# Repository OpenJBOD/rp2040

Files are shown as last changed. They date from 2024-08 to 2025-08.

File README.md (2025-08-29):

# OpenJBOD RP2040 Baseboard

This repository contains the hardware design files OpenJBOD RP2040 Baseboard.

For the accompanying software, please refer to:
- [micropython/micropython](https://github.com/micropython/micropython)
- [OpenJBOD/software](https://github.com/OpenJBOD/software)

## Requirements

- The design was created on KiCad 8.0.2, it uses the default symbol and footprint libraries from it. If you have installed KiCad without the default libraries, you may experience missing symbols.
- Non-standard symbols, footprints and models are bundled in the repository and should load with the project.

## Compatibility

The board is compatible with any standards-compliant ATX power supply.

For SAS expanders, any SAS expander that can operate with only power (i.e. no PCI-e communication) should be functional on the board.

The board has successfully been tested with:

- Adaptec AEC-82885T

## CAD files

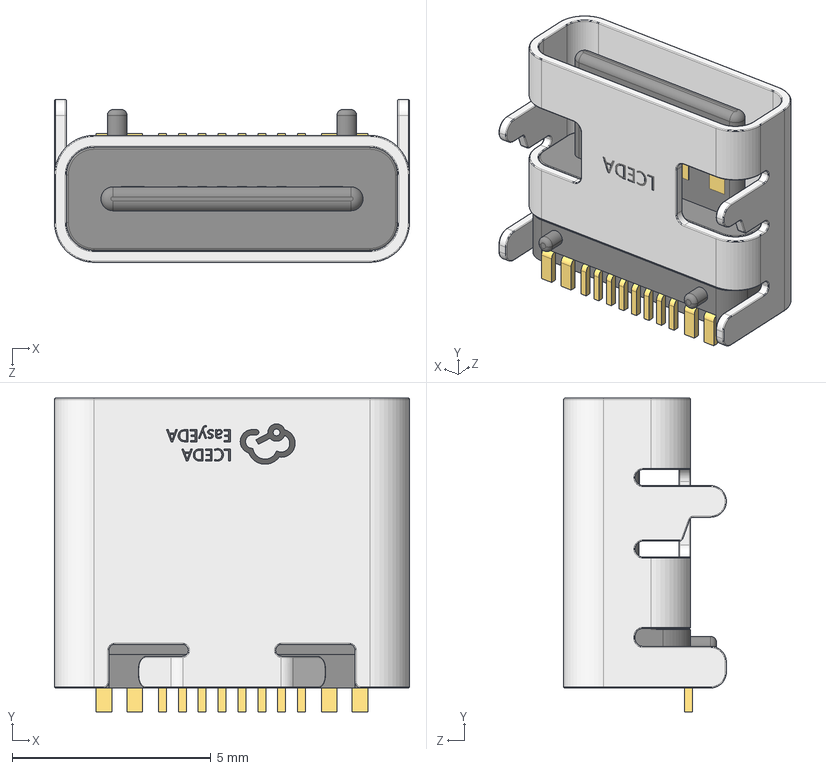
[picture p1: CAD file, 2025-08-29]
OpenJBOD.3d/USB-C-SMD_TYPE-C16PIN.step
8.94 x 7.90 x 4.10 mm

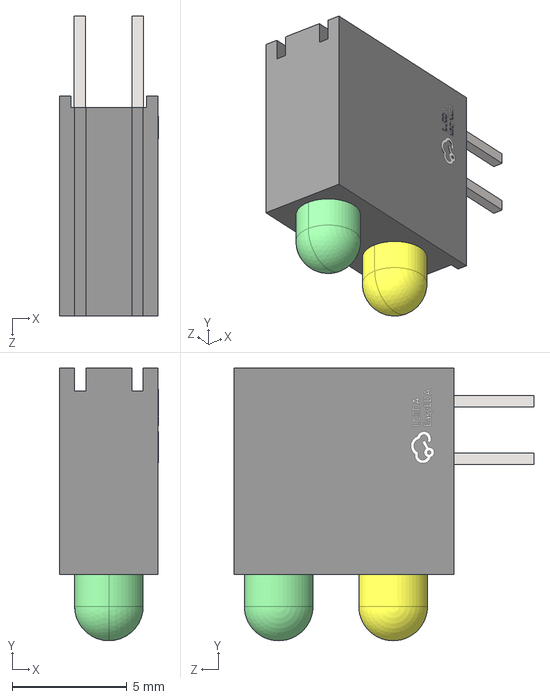
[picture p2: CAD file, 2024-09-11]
OpenJBOD.3d/LED-TH_MHK2396YGBTD.step
4.31 x 11.9 x 13.1 mm

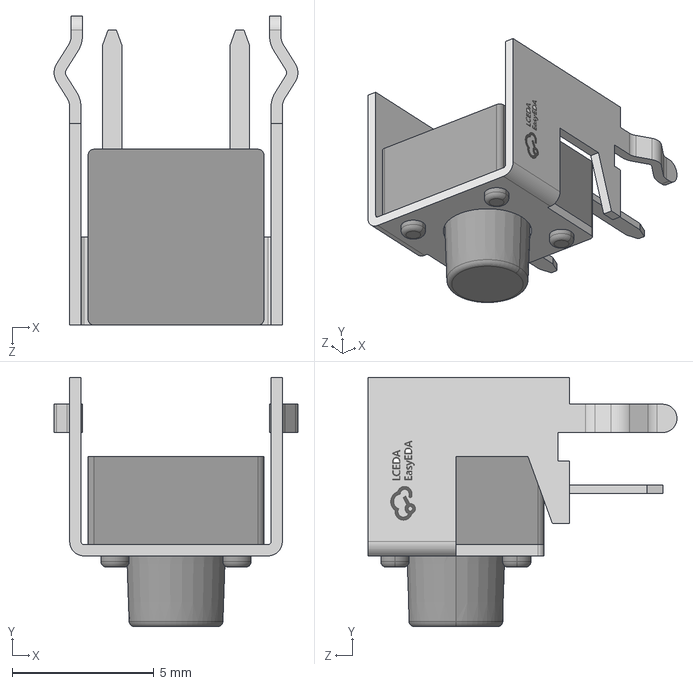
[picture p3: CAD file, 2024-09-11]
OpenJBOD.3d/KEY-TH_TC-6615-6-160G.step
8.60 x 8.80 x 10.9 mm

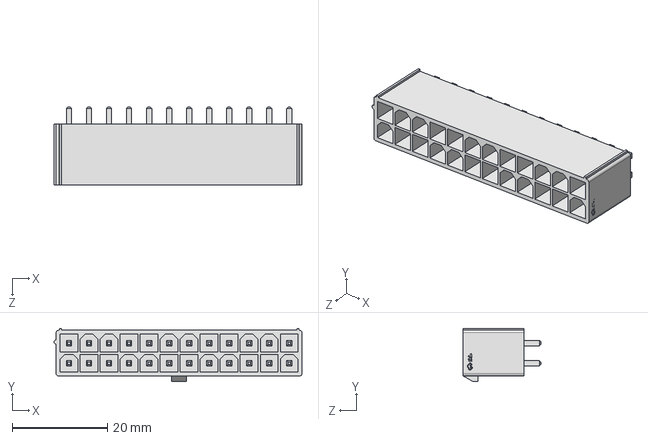
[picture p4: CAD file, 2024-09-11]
OpenJBOD.3d/CONN-TH_M4202V-2X12P.step
52.0 x 11.2 x 16.3 mm

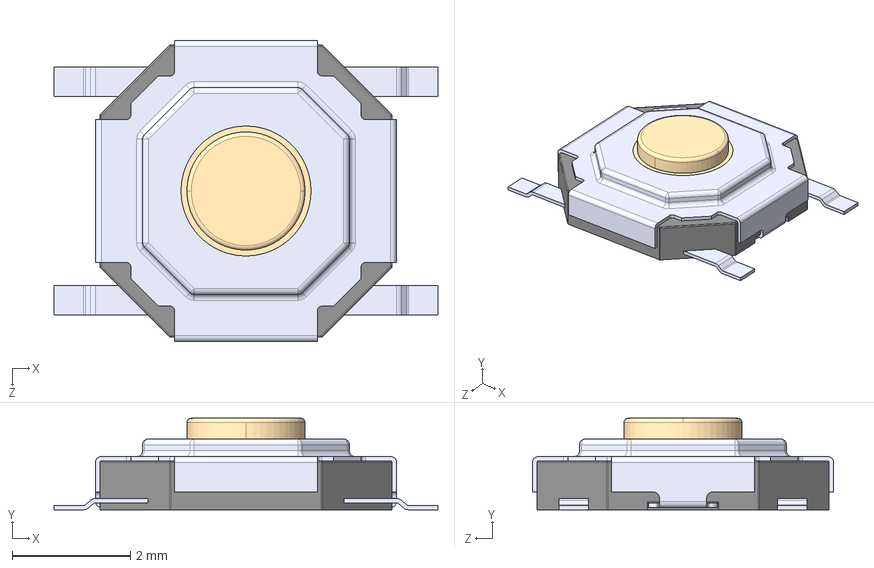
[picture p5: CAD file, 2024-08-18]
OpenJBOD.3d/TS-1187A-B-A-B.STEP
6.50 x 1.55 x 5.10 mm

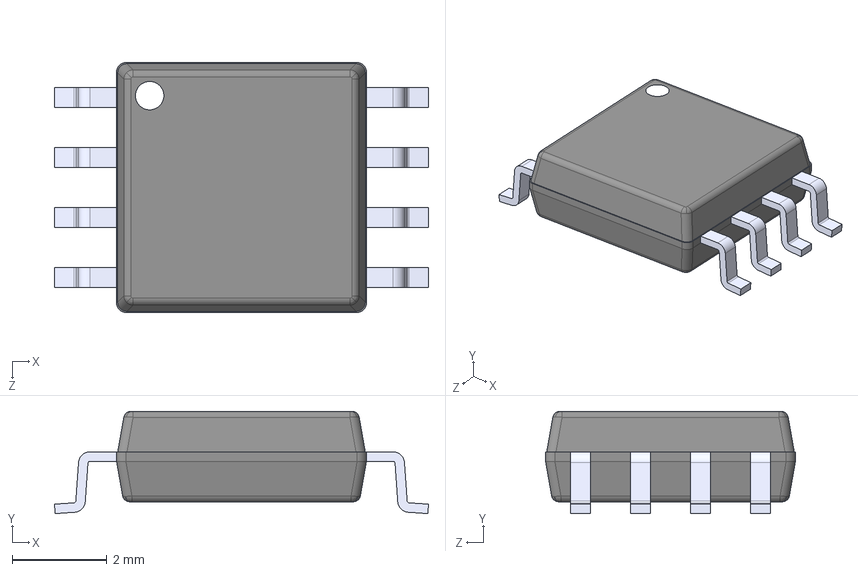
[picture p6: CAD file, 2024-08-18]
OpenJBOD.3d/W25Q128JVSIM TR.STEP
7.90 x 2.16 x 5.28 mm

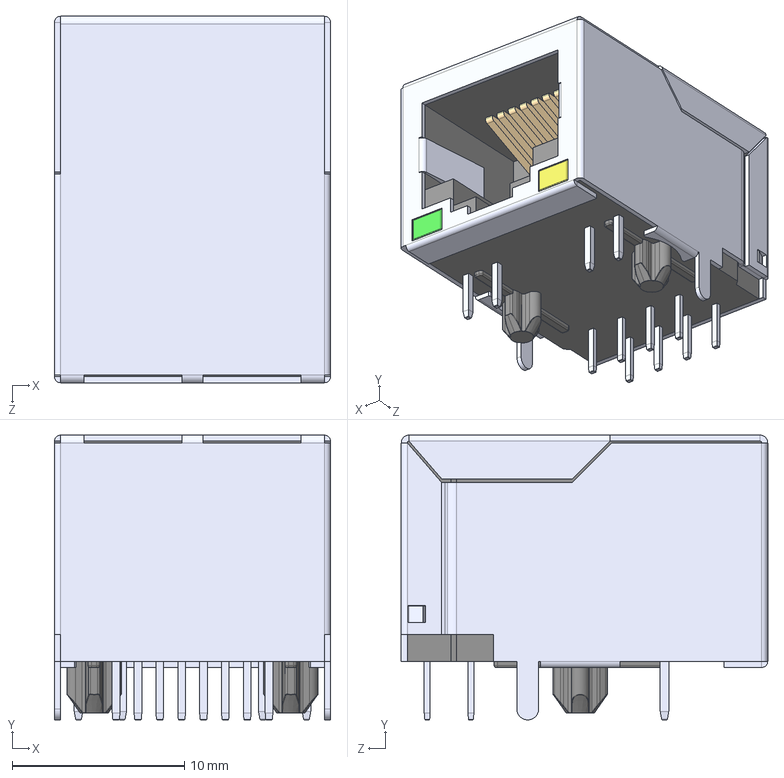
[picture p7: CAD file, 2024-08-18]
OpenJBOD.3d/HR911105A.STEP
16.0 x 16.6 x 21.3 mm

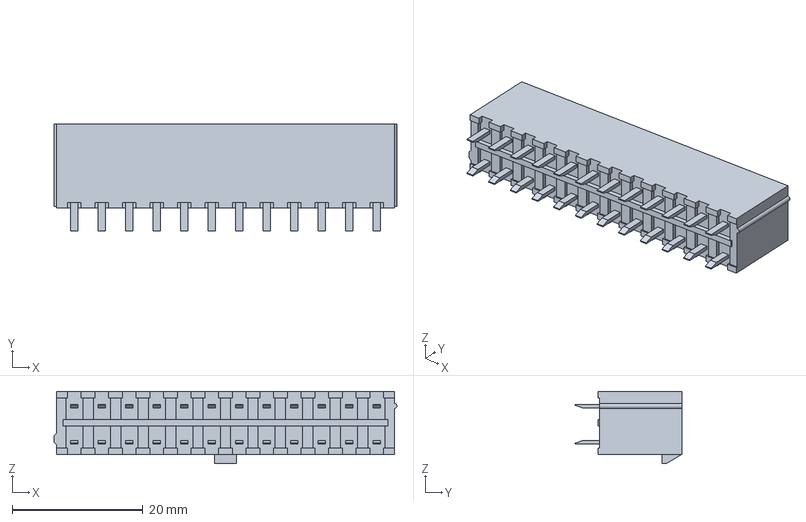
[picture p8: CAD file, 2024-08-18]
OpenJBOD.3d/039281243.stp
52.4 x 16.3 x 11.0 mm

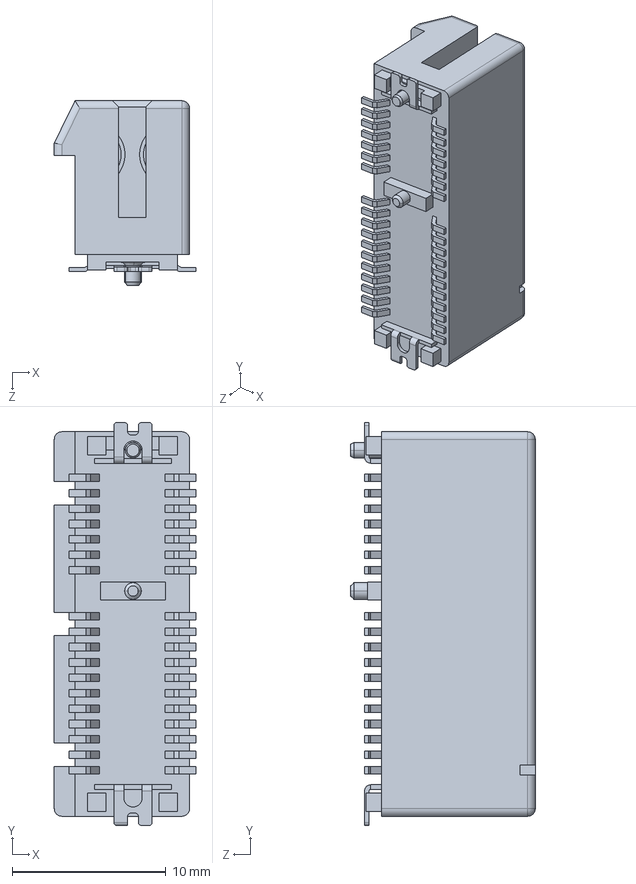
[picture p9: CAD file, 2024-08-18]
OpenJBOD.3d/91618-X1.STEP
9.20 x 26.2 x 12.0 mm

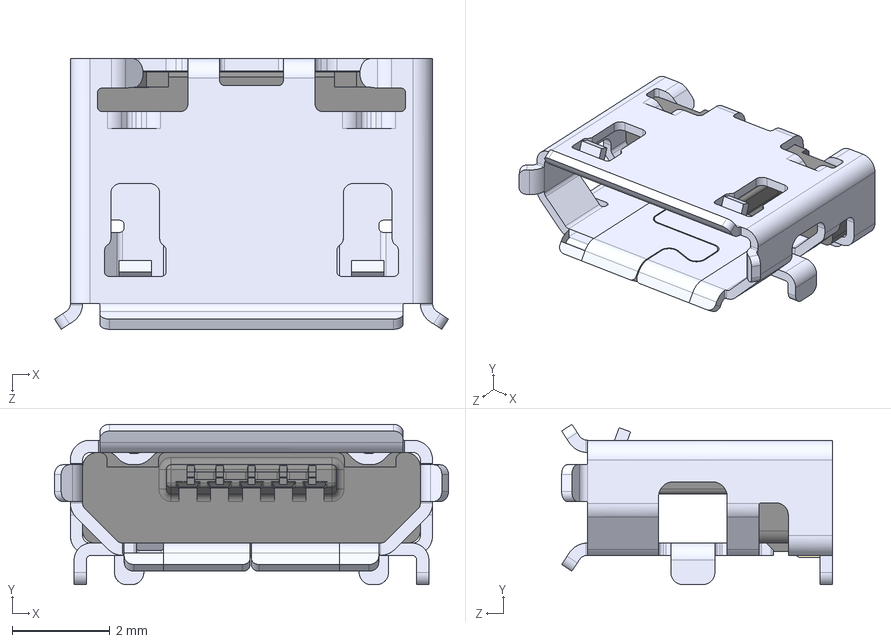
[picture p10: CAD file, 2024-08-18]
OpenJBOD.3d/10118194-0001LF.STEP
8.05 x 3.27 x 5.53 mm

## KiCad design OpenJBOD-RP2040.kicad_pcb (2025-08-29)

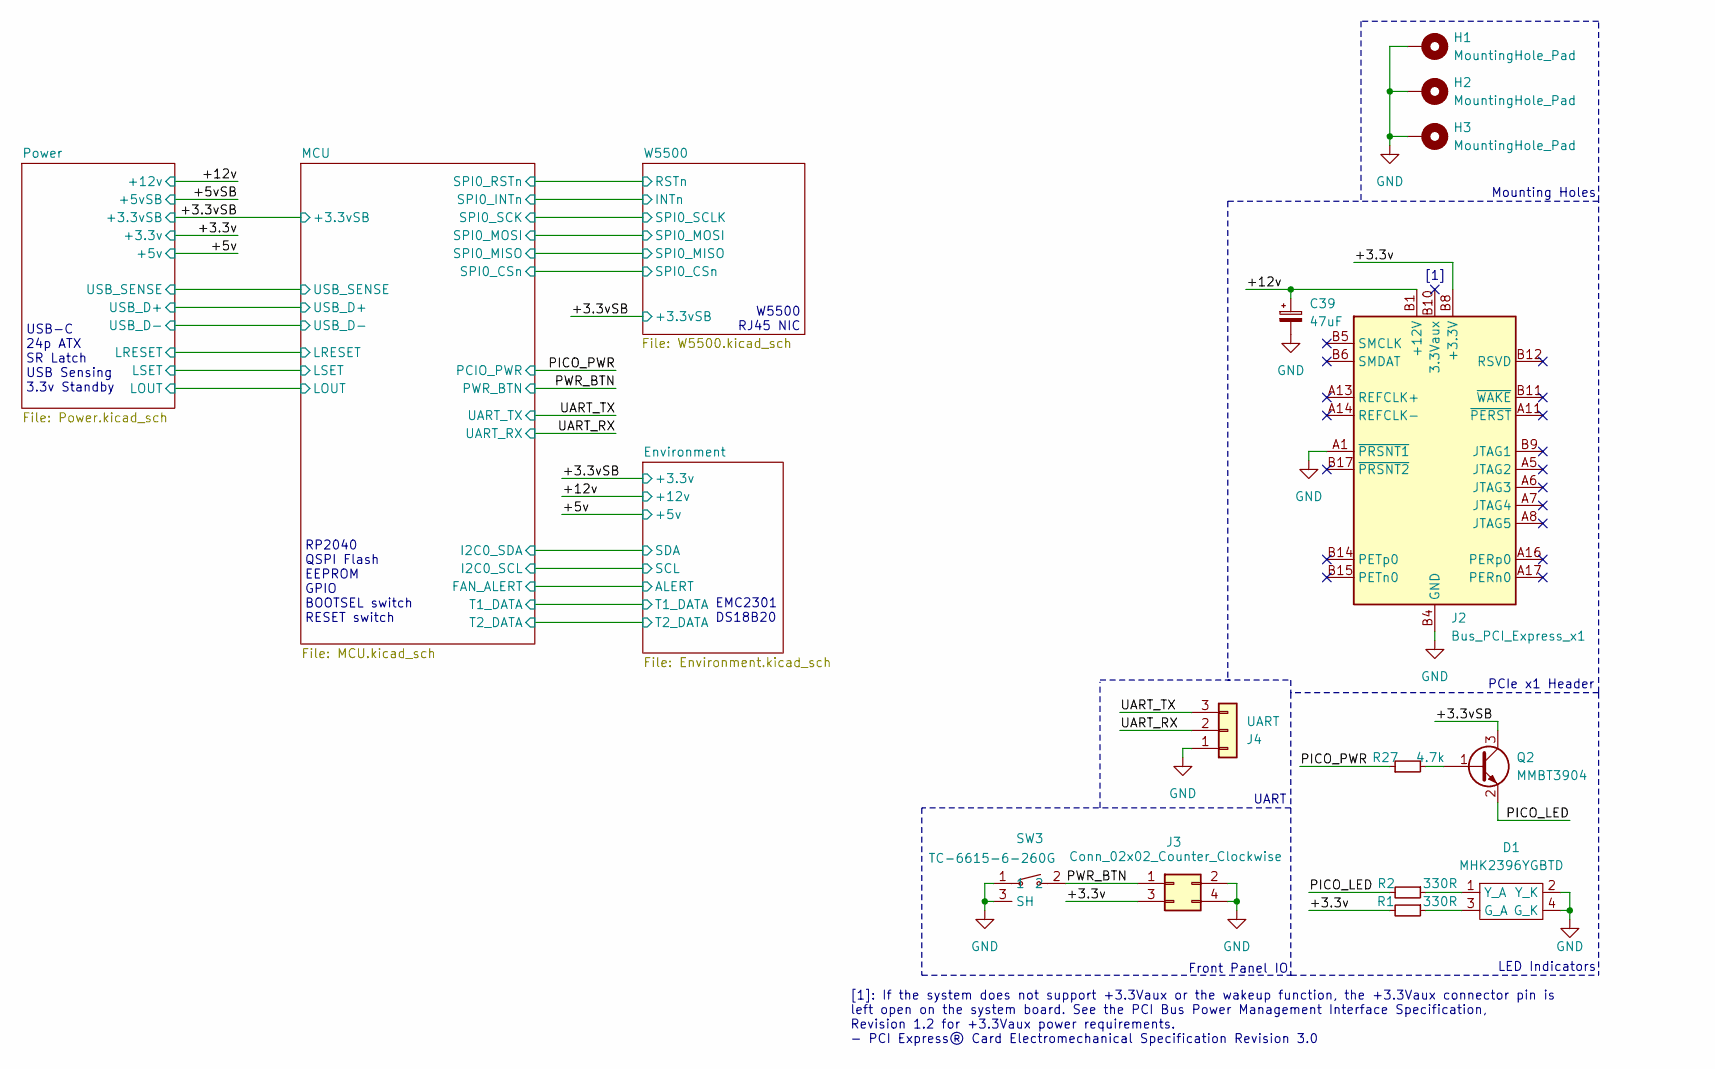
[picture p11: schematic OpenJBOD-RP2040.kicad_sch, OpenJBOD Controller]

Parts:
C39: 47uF; CP_Elec_6.3x5.4; LCSC Part # C2836440
D1: MHK2396YGBTD; LED-TH_MHK2396YGBTD; LCSC Part # C2764899
H1, H2, H3: MountingHole_Pad; MountingHole_4.3mm_M4_Pad_Via
J2: Bus_PCI_Express_x1; 91618-11010C; LCSC Part # C5210918
J3: Conn_02x02_Counter_Clockwise; PinHeader_2x02_P2.54mm_Vertical; LCSC Part # C492419
J4: UART; PinHeader_1x03_P2.54mm_Horizontal; LCSC Part # C2894945
Q2: MMBT3904; SOT-23; LCSC Part # C20526
R1, R2: 330R; R_0402_1005Metric; LCSC Part # C25104
R27: 4.7k; R_0402_1005Metric; LCSC Part # C25900
SW3: TC-6615-6-260G; KEY-TH_TC-6615-6-160G; LCSC Part # C2845272

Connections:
/+3.3v: J2.A9 (+3.3V), J2.A10 (+3.3V), J2.B8 (+3.3V), J3.3, R1.2; also elsewhere on the board
/+3.3vSB: Q2.3 (C); also elsewhere on the board
/+12v: C39.1, J2.A2 (+12V), J2.A3 (+12V), J2.B1 (+12V), J2.B2 (+12V), J2.B3 (+12V); also elsewhere on the board
/PICO_LED: Q2.2 (E), R2.2
/PICO_PWR: R27.1; also elsewhere on the board
/PWR_BTN: J3.1, SW3.2; also elsewhere on the board
/UART_RX: J4.2; also elsewhere on the board
/UART_TX: J4.3; also elsewhere on the board
GND: C39.2, D1.2 (Y_K), D1.4 (G_K), H1.1, H2.1, H3.1, J2.A1 (~PRSNT1), J2.A4 (GND), J2.A12 (GND), J2.A15 (GND), J2.A18 (GND), J2.B4 (GND), J2.B7 (GND), J2.B13 (GND), J2.B16 (GND), J2.B18 (GND), J3.2, J3.4, J4.1, SW3.1, SW3.3 (SH), SW3.4 (SH); also elsewhere on the board
unnamed: D1.3 (G_A), R1.1
unnamed: D1.1 (Y_A), R2.1
unnamed: Q2.1 (B), R27.2

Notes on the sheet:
UART
RP2040 QSPI Flash EEPROM GPIO BOOTSEL switch RESET switch
Mounting Holes
Front Panel IO
EMC2301 DS18B20
LED Indicators
W5500 RJ45 NIC
USB-C 24p ATX SR Latch USB Sensing 3.3v Standby
PCIe x1 Header
[1]: If the system does not support +3.3Vaux or the wakeup function, the +3.3Vaux connector pin is left open on the system board. See the PCI Bus Power Management Interface Specification, Revision 1.2 for +3.3Vaux power requirements. - PCI Express® Card Electromechanical Specification Revision 3.0
[1]

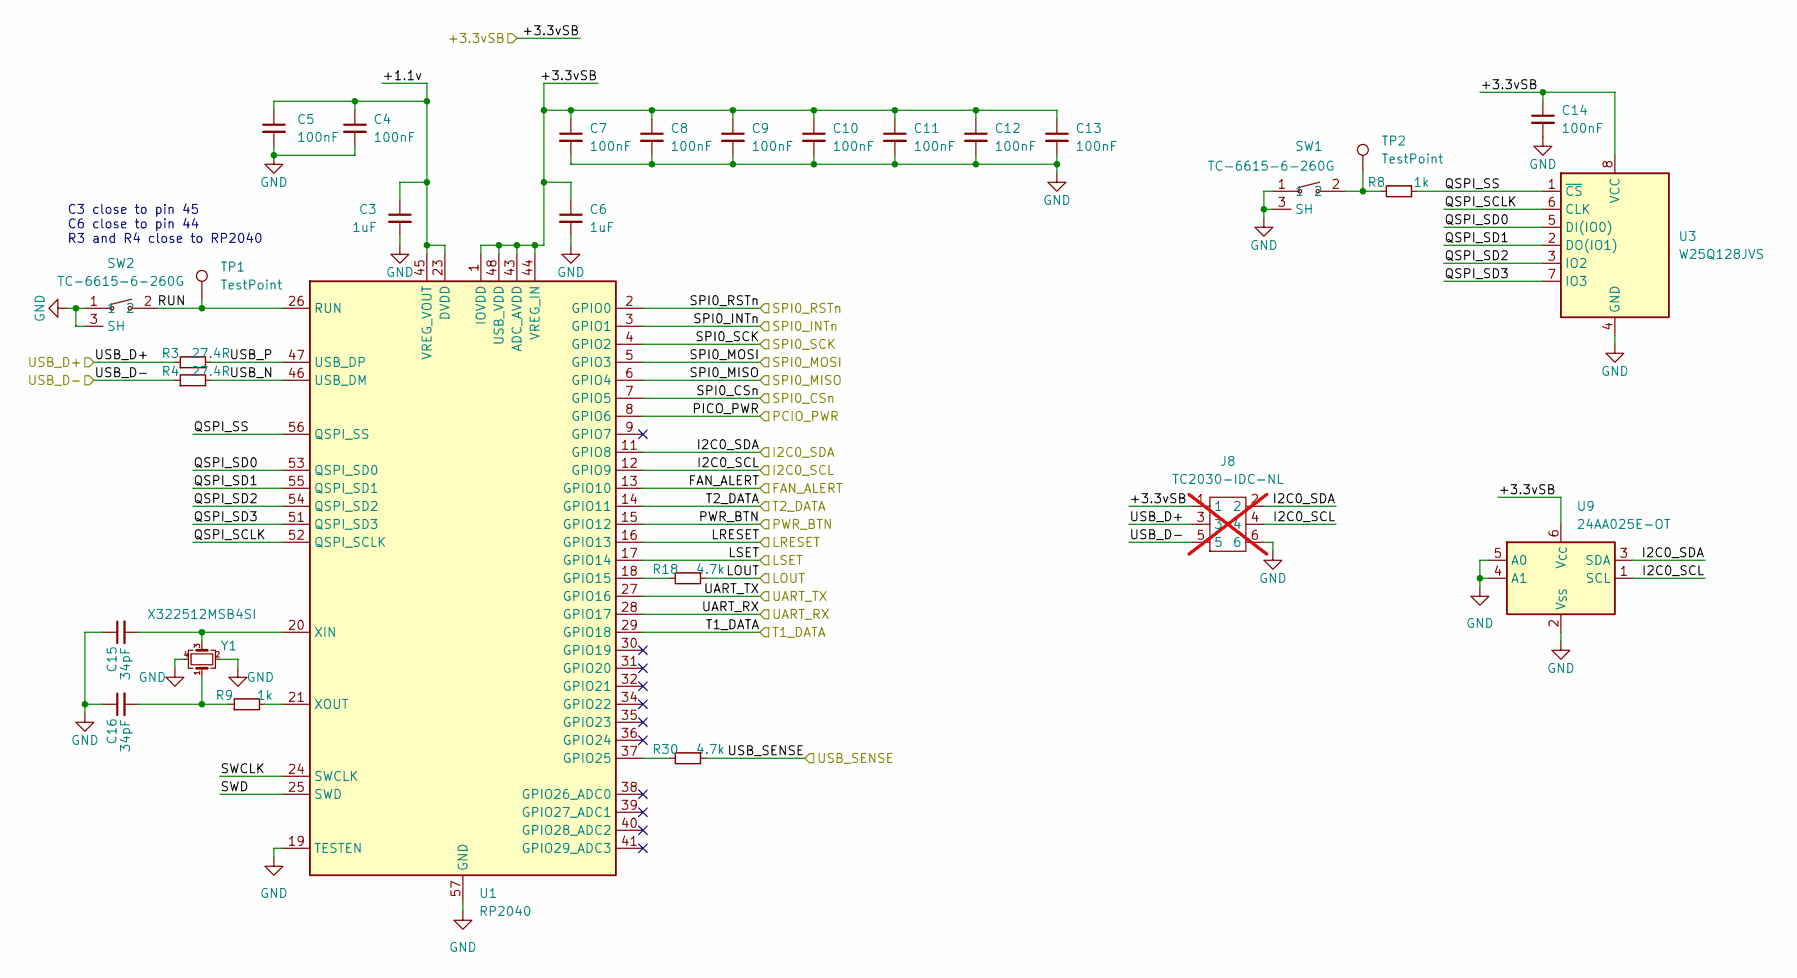
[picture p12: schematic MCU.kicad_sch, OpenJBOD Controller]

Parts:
C3, C6: 1uF; C_0402_1005Metric; LCSC Part # C52923
C4, C5, C7, C8, C9, C10, C11, C12, C13, C14: 100nF; C_0402_1005Metric; LCSC Part # C1525
C15, C16: 34pF; C_0603_1608Metric; LCSC Part # C1658
J8: TC2030-IDC-NL; Tag-Connect_TC2030-IDC-NL_2x03_P1.27mm_Vertical; not fitted
R3, R4: 27.4R; R_0402_1005Metric; LCSC Part # C284479
R8, R9: 1k; R_0402_1005Metric; LCSC Part # C11702
R18, R30: 4.7k; R_0402_1005Metric; LCSC Part # C25900
SW1, SW2: TC-6615-6-260G; KEY-TH_TC-6615-6-160G; LCSC Part # C2845272
TP1, TP2: TestPoint; TestPoint_Pad_D1.0mm
U1: RP2040; QFN-56-1EP_7x7mm_P0.4mm_EP3.2x3.2mm; LCSC Part # C2040
U3: W25Q128JVS; SOIC-8_5.23x5.23mm_P1.27mm; LCSC Part # C97521
U9: 24AA025E-OT; SOT-23-6; LCSC Part # C129895
Y1: X322512MSB4SI; Crystal_SMD_3225-4Pin_3.2x2.5mm; LCSC Part # C9002

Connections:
/+3.3vSB: C6.1, C7.1, C8.1, C9.1, C10.1, C11.1, C12.1, C13.1, C14.1, J8.1, U1.1 (IOVDD), U1.10 (IOVDD), U1.22 (IOVDD), U1.33 (IOVDD), U1.42 (IOVDD), U1.43 (ADC_AVDD), U1.44 (VREG_IN), U1.48 (USB_VDD), U1.49 (IOVDD), U3.8 (VCC), U9.6 (V_{CC}); also elsewhere on the board
/Environment/ALERT: U1.13 (GPIO10); also elsewhere on the board
/Environment/SCL: J8.4, U1.12 (GPIO9), U9.1 (SCL); also elsewhere on the board
/Environment/SDA: J8.2, U1.11 (GPIO8), U9.3 (SDA); also elsewhere on the board
/Environment/T1_DATA: U1.29 (GPIO18); also elsewhere on the board
/Environment/T2_DATA: U1.14 (GPIO11); also elsewhere on the board
/MCU/+1.1v: C3.1, C4.1, C5.1, U1.23 (DVDD), U1.45 (VREG_VOUT), U1.50 (DVDD)
/MCU/LOUT: R18.1; also elsewhere on the board
/MCU/LRESET: U1.16 (GPIO13); also elsewhere on the board
/MCU/LSET: U1.17 (GPIO14); also elsewhere on the board
/MCU/QSPI_SCLK: U1.52 (QSPI_SCLK), U3.6 (CLK)
/MCU/QSPI_SD0: U1.53 (QSPI_SD0), U3.5 (DI(IO0))
/MCU/QSPI_SD1: U1.55 (QSPI_SD1), U3.2 (DO(IO1))
/MCU/QSPI_SD2: U1.54 (QSPI_SD2), U3.3 (IO2)
/MCU/QSPI_SD3: U1.51 (QSPI_SD3), U3.7 (IO3)
/MCU/QSPI_SS: R8.1, U1.56 (QSPI_SS), U3.1 (~CS)
/MCU/RUN: SW2.2, TP1.1, U1.26 (RUN)
/MCU/SPI0_CSn: U1.7 (GPIO5); also elsewhere on the board
/MCU/SPI0_INTn: U1.3 (GPIO1); also elsewhere on the board
/MCU/SPI0_MISO: U1.6 (GPIO4); also elsewhere on the board
/MCU/SPI0_MOSI: U1.5 (GPIO3); also elsewhere on the board
/MCU/SPI0_RSTn: U1.2 (GPIO0); also elsewhere on the board
/MCU/SPI0_SCK: U1.4 (GPIO2); also elsewhere on the board
/MCU/SWCLK: U1.24 (SWCLK)
/MCU/SWD: U1.25 (SWD)
/MCU/USB_D+: J8.3, R3.1; also elsewhere on the board
/MCU/USB_D-: J8.5, R4.1; also elsewhere on the board
/MCU/USB_N: R4.2, U1.46 (USB_DM)
/MCU/USB_P: R3.2, U1.47 (USB_DP)
/MCU/USB_SENSE: R30.1; also elsewhere on the board
/PICO_PWR: U1.8 (GPIO6); also elsewhere on the board
/PWR_BTN: U1.15 (GPIO12); also elsewhere on the board
/UART_RX: U1.28 (GPIO17); also elsewhere on the board
/UART_TX: U1.27 (GPIO16); also elsewhere on the board
GND: C3.2, C4.2, C5.2, C6.2, C7.2, C8.2, C9.2, C10.2, C11.2, C12.2, C13.2, C14.2, C15.1, C16.1, J8.6, SW1.1, SW1.3 (SH), SW1.4 (SH), SW2.1, SW2.3 (SH), SW2.4 (SH), U1.19 (TESTEN), U1.57 (GND), U3.4 (GND), U9.2 (V_{SS}), U9.4 (A1), U9.5 (A0), Y1.2, Y1.4; also elsewhere on the board
unnamed: C16.2, R9.1, Y1.1
unnamed: R8.2, SW1.2, TP2.1
unnamed: R18.2, U1.18 (GPIO15)
unnamed: R30.2, U1.37 (GPIO25)
unnamed: C15.2, U1.20 (XIN), Y1.3
unnamed: R9.2, U1.21 (XOUT)

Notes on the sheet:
C3 close to pin 45 C6 close to pin 44 R3 and R4 close to RP2040

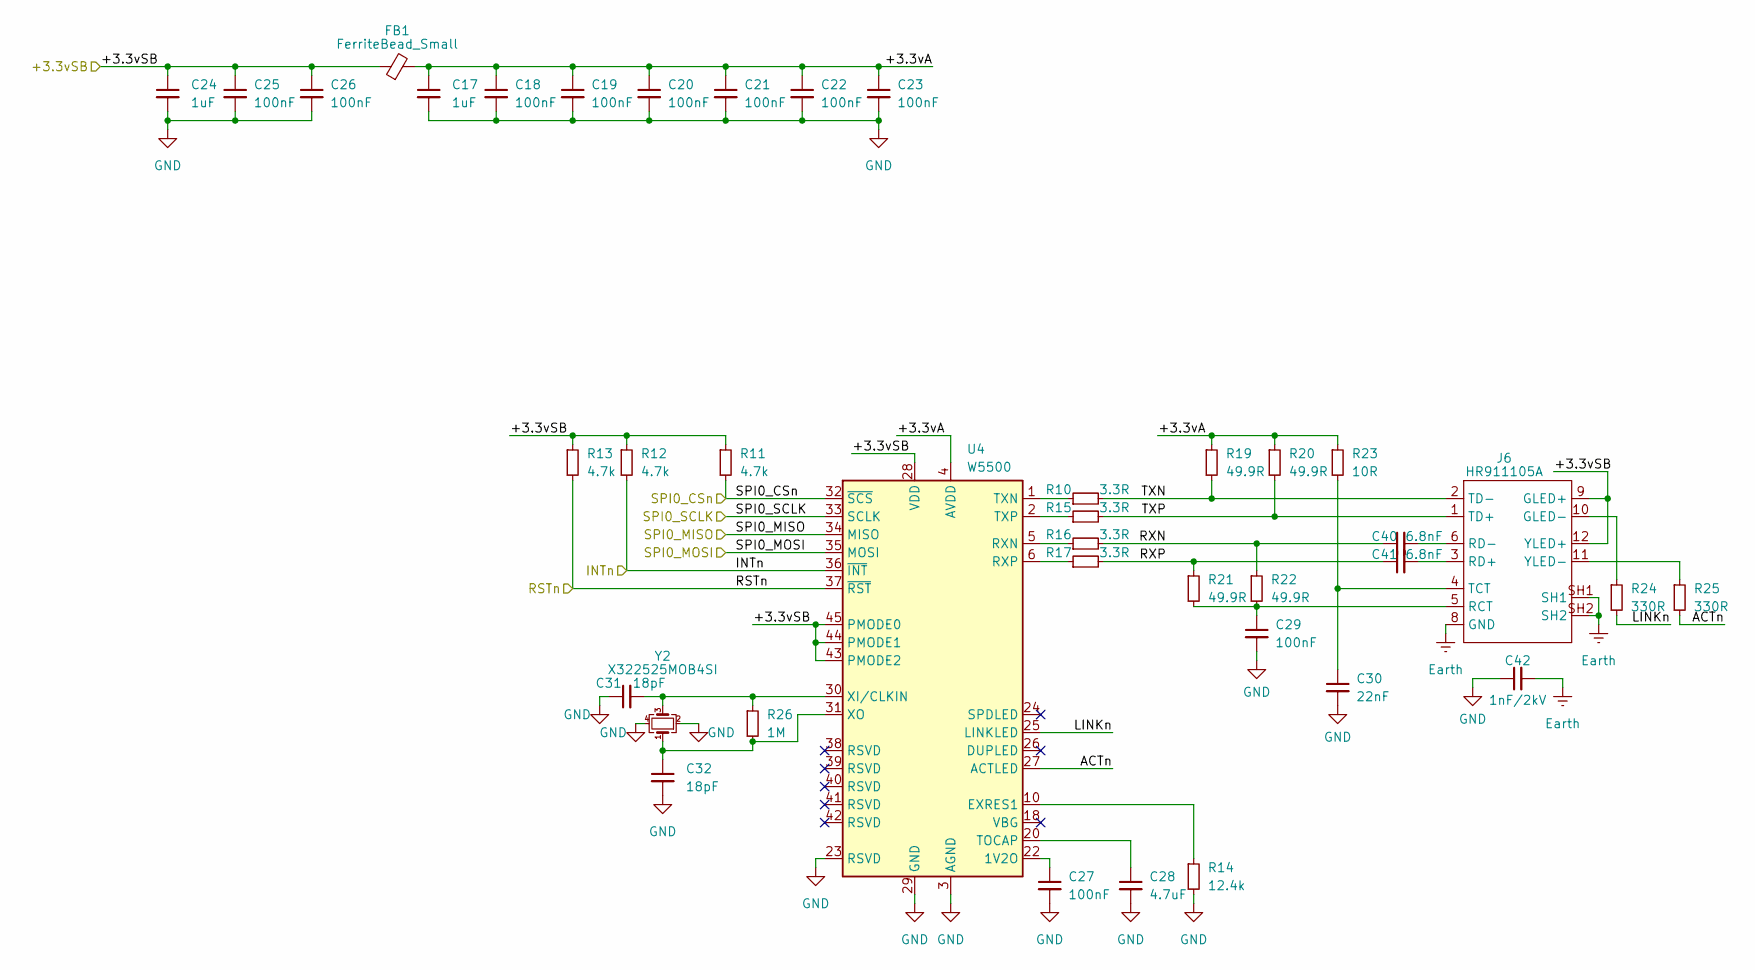
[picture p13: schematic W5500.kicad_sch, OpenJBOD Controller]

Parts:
C17, C24: 1uF; C_0402_1005Metric; LCSC Part # C52923
C18, C19, C20, C21, C22, C23, C25, C26, C27, C29: 100nF; C_0402_1005Metric; LCSC Part # C1525
C28: 4.7uF; C_0402_1005Metric; LCSC Part # C23733
C30: 22nF; C_0402_1005Metric; LCSC Part # C1532
C31, C32: 18pF; C_0402_1005Metric; LCSC Part # C1549
C40, C41: 6.8nF; C_0402_1005Metric; LCSC Part # C1542
C42: 1nF/2kV; C_1206_3216Metric; LCSC Part # C9196
FB1: FerriteBead_Small; C_0805_2012Metric_Pad1.18x1.45mm_HandSolder; LCSC Part # C1015
J6: HR911105A; RJ45-TH_HR911105A; LCSC Part # C12074
R10, R15, R16, R17: 3.3R; R_0603_1608Metric; LCSC Part # C2930016
R11, R12, R13: 4.7k; R_0402_1005Metric; LCSC Part # C25900
R14: 12.4k; R_0402_1005Metric; LCSC Part # C11692
R19, R20, R21, R22: 49.9R; R_0402_1005Metric; LCSC Part # C25120
R23: 10R; R_0402_1005Metric; LCSC Part # C25077
R24, R25: 330R; R_0402_1005Metric; LCSC Part # C25104
R26: 1M; R_0402_1005Metric; LCSC Part # C26083
U4: W5500; LQFP-48_7x7mm_P0.5mm; LCSC Part # C32843
Y2: X322525MOB4SI; Crystal_SMD_3225-4Pin_3.2x2.5mm; LCSC Part # C9006

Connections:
/+3.3vSB: C24.1, C25.1, C26.1, FB1.1, J6.9 (GLED+), J6.12 (YLED+), R11.1, R12.1, R13.1, U4.28 (VDD), U4.43 (PMODE2), U4.44 (PMODE1), U4.45 (PMODE0); also elsewhere on the board
/MCU/SPI0_CSn: R11.2, U4.32 (~SCS); also elsewhere on the board
/MCU/SPI0_INTn: R12.2, U4.36 (~INT); also elsewhere on the board
/MCU/SPI0_MISO: U4.34 (MISO); also elsewhere on the board
/MCU/SPI0_MOSI: U4.35 (MOSI); also elsewhere on the board
/MCU/SPI0_RSTn: R13.2, U4.37 (~RST); also elsewhere on the board
/MCU/SPI0_SCK: U4.33 (SCLK); also elsewhere on the board
/W5500/+3.3vA: C17.1, C18.1, C19.1, C20.1, C21.1, C22.1, C23.1, FB1.2, R19.1, R20.1, R23.1, U4.4 (AVDD), U4.8 (AVDD), U4.11 (AVDD), U4.15 (AVDD), U4.17 (AVDD), U4.21 (AVDD)
/W5500/ACTn: R25.2, U4.27 (ACTLED)
/W5500/LINKn: R24.2, U4.25 (LINKLED)
/W5500/RXN: C40.1, R16.2, R22.1
/W5500/RXP: C41.1, R17.2, R21.1
/W5500/TXN: J6.2 (TD-), R10.2, R19.2
/W5500/TXP: J6.1 (TD+), R15.2, R20.2
Earth: C42.2, J6.8 (GND), J6.SH1, J6.SH2
GND: C17.2, C18.2, C19.2, C20.2, C21.2, C22.2, C23.2, C24.2, C25.2, C26.2, C27.2, C28.2, C29.2, C30.2, C31.1, C32.2, C42.1, R14.2, U4.3 (AGND), U4.9 (AGND), U4.14 (AGND), U4.16 (AGND), U4.19 (AGND), U4.23 (RSVD), U4.29 (GND), U4.48 (AGND), Y2.2, Y2.4; also elsewhere on the board
unnamed: J6.10 (GLED-), R24.1
unnamed: C29.1, J6.5 (RCT), R21.2, R22.2
unnamed: C41.2, J6.3 (RD+)
unnamed: C40.2, J6.6 (RD-)
unnamed: C30.1, J6.4 (TCT), R23.2
unnamed: J6.11 (YLED-), R25.1
unnamed: C27.1, U4.22 (1V2O)
unnamed: R14.1, U4.10 (EXRES1)
unnamed: R16.1, U4.5 (RXN)
unnamed: R17.1, U4.6 (RXP)
unnamed: C28.1, U4.20 (TOCAP)
unnamed: R10.1, U4.1 (TXN)
unnamed: R15.1, U4.2 (TXP)
unnamed: C31.2, R26.1, U4.30 (XI/CLKIN), Y2.3
unnamed: C32.1, R26.2, U4.31 (XO), Y2.1

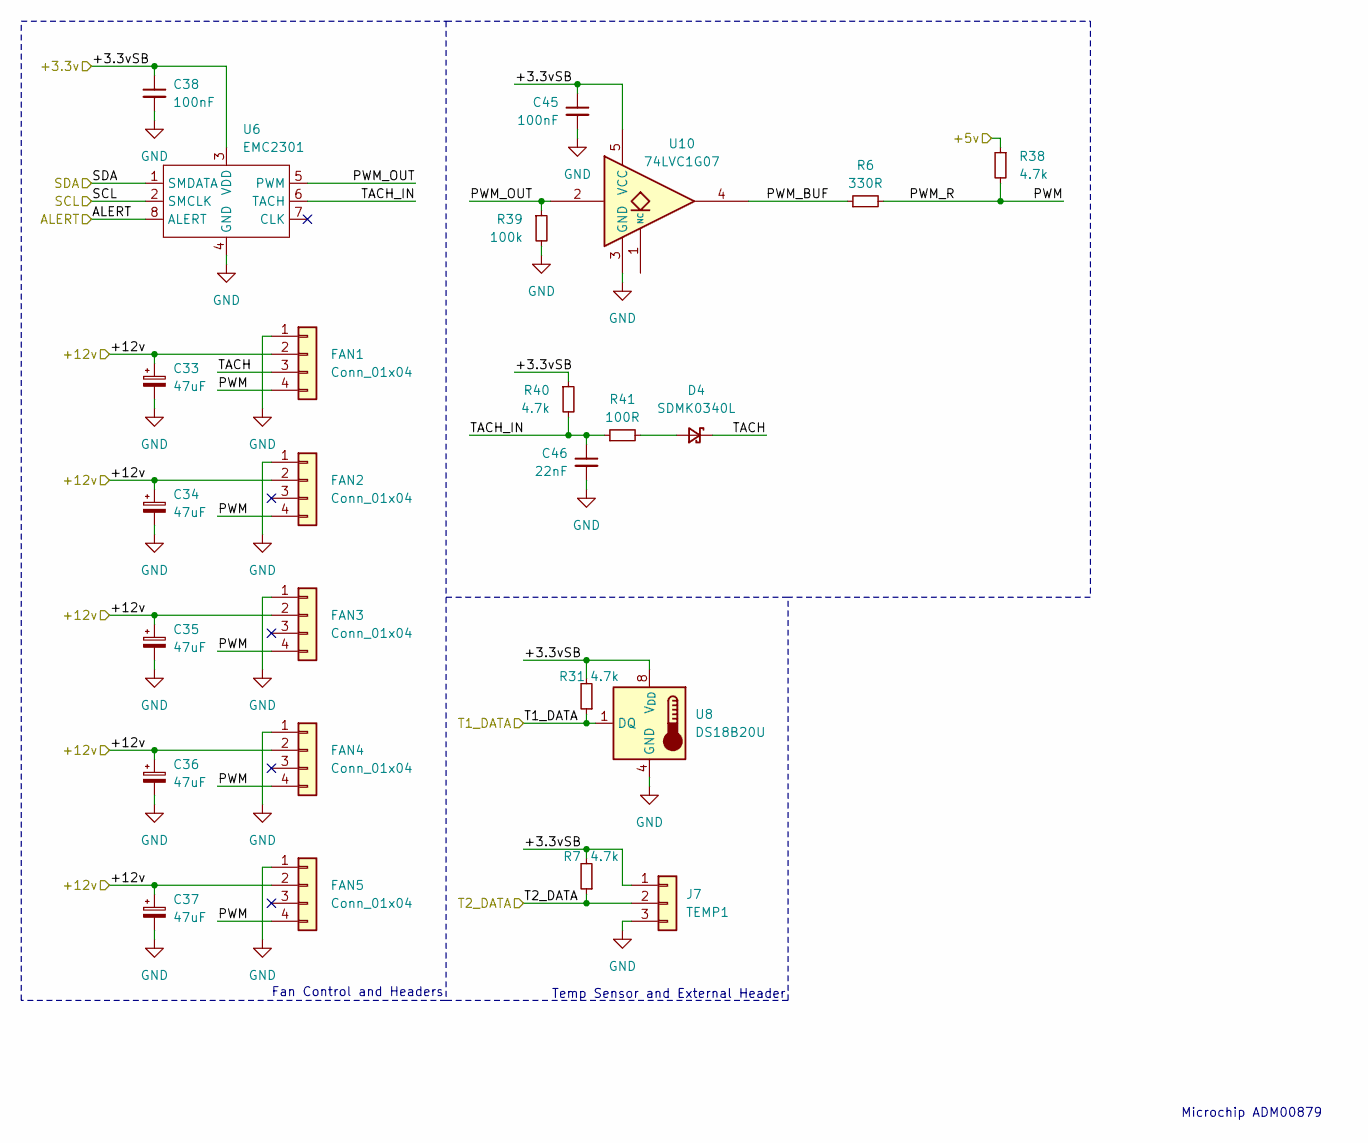
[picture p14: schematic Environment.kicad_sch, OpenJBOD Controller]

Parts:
C33, C34, C35, C36, C37: 47uF; CP_Elec_6.3x5.4; LCSC Part # C2836440
C38, C45: 100nF; C_0402_1005Metric; LCSC Part # C1525
C46: 22nF; C_0402_1005Metric; LCSC Part # C1532
D4: SDMK0340L; D_SOD-323; LCSC Part # C139440
FAN1, FAN2, FAN3, FAN4, FAN5: Conn_01x04; FanPinHeader_1x04_P2.54mm_Vertical; LCSC Part # C240840
J7: TEMP1; PinHeader_1x03_P2.54mm_Vertical; LCSC Part # C2937625
R6: 330R; R_0402_1005Metric; LCSC Part # C25104
R7, R31, R38, R40: 4.7k; R_0402_1005Metric; LCSC Part # C25900
R39: 100k; C_0402_1005Metric; LCSC Part # C25741
R41: 100R; C_0402_1005Metric; LCSC Part # C25076
U6: EMC2301; MSOP-8_3x3mm_P0.65mm; LCSC Part # C148036
U8: DS18B20U; MSOP-8_3x3mm_P0.65mm; LCSC Part # C695836
U10: 74LVC1G07; SOT-23-5; LCSC Part # C7829

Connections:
/+3.3vSB: C38.1, C45.1, J7.1, R7.2, R31.2, R40.1, U6.3 (VDD), U8.8 (V_{DD}), U10.5 (VCC); also elsewhere on the board
/+5v: R38.1; also elsewhere on the board
/+12v: C33.1, C34.1, C35.1, C36.1, C37.1, FAN1.2, FAN2.2, FAN3.2, FAN4.2, FAN5.2; also elsewhere on the board
/Environment/ALERT: U6.8 (ALERT); also elsewhere on the board
/Environment/PWM: FAN1.4, FAN2.4, FAN3.4, FAN4.4, FAN5.4, R6.2, R38.2
/Environment/PWM_BUF: R6.1, U10.4
/Environment/PWM_OUT: R39.1, U6.5 (PWM), U10.2
/Environment/SCL: U6.2 (SMCLK); also elsewhere on the board
/Environment/SDA: U6.1 (SMDATA); also elsewhere on the board
/Environment/T1_DATA: R31.1, U8.1 (DQ); also elsewhere on the board
/Environment/T2_DATA: J7.2, R7.1; also elsewhere on the board
/Environment/TACH: D4.1 (K), FAN1.3
/Environment/TACH_IN: C46.1, R40.2, R41.1, U6.6 (TACH)
GND: C33.2, C34.2, C35.2, C36.2, C37.2, C38.2, C45.2, C46.2, FAN1.1, FAN2.1, FAN3.1, FAN4.1, FAN5.1, J7.3, R39.2, U6.4 (GND), U8.4 (GND), U10.3 (GND); also elsewhere on the board
unnamed: D4.2 (A), R41.2

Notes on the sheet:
Temp Sensor and External Header
Microchip ADM00879
Fan Control and Headers

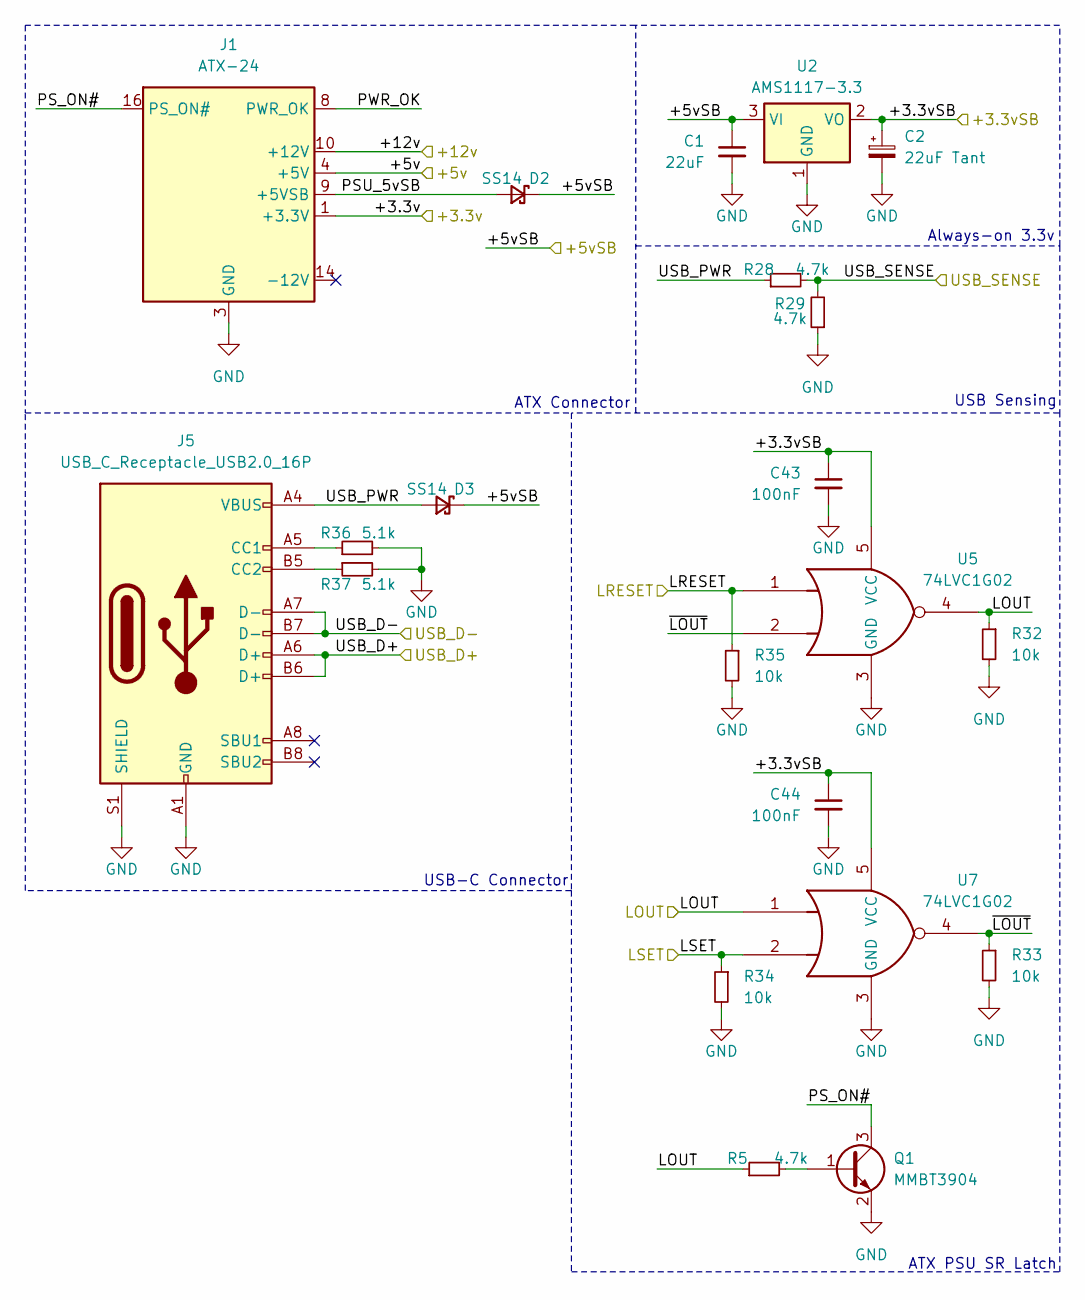
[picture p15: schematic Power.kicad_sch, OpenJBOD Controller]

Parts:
C1: 22uF; C_1206_3216Metric; LCSC Part # C12891
C2: 22uF Tant; CP_EIA-3216-18_Kemet-A; LCSC Part # C11366
C43, C44: 100nF; C_0402_1005Metric; LCSC Part # C1525
D2, D3: SS14; D_SMA; LCSC Part # C2480
J1: ATX-24; CONN-TH_M4202V-2X12P; LCSC Part # C492535
J5: USB_C_Receptacle_USB2.0_16P; USB-C-SMD_TYPE-C16PIN; LCSC Part # C393939
Q1: MMBT3904; SOT-23; LCSC Part # C20526
R5, R28, R29: 4.7k; R_0402_1005Metric; LCSC Part # C25900
R32, R33, R34, R35: 10k; C_0402_1005Metric; LCSC Part # C25744
R36, R37: 5.1k; C_0402_1005Metric; LCSC Part # C25905
U2: AMS1117-3.3; SOT-223-3_TabPin2; LCSC Part # C6186
U5, U7: 74LVC1G02; SOT-353_SC-70-5; LCSC Part # C353856

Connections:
/+3.3v: J1.1 (+3.3V), J1.2 (+3.3V), J1.12 (+3.3V), J1.13 (+3.3V); also elsewhere on the board
/+3.3vSB: C2.1, C43.1, C44.1, U2.2 (VO), U5.5 (VCC), U7.5 (VCC); also elsewhere on the board
/+5v: J1.4 (+5V), J1.6 (+5V), J1.21 (+5V), J1.22 (+5V), J1.23 (+5V); also elsewhere on the board
/+5vSB: C1.1, D2.1 (K), D3.1 (K), U2.3 (VI)
/+12v: J1.10 (+12V), J1.11 (+12V); also elsewhere on the board
/MCU/LOUT: R5.1, R32.1, U5.4, U7.1; also elsewhere on the board
/MCU/LRESET: R35.1, U5.1; also elsewhere on the board
/MCU/LSET: R34.1, U7.2; also elsewhere on the board
/MCU/USB_D+: J5.A6 (D+), J5.B6 (D+); also elsewhere on the board
/MCU/USB_D-: J5.A7 (D-), J5.B7 (D-); also elsewhere on the board
/MCU/USB_SENSE: R28.2, R29.2; also elsewhere on the board
/Power/PSU_5vSB: D2.2 (A), J1.9 (+5VSB)
/Power/PS_ON#: J1.16 (PS_ON#), Q1.3 (C)
/Power/PWR_OK: J1.8 (PWR_OK)
/Power/USB_PWR: D3.2 (A), J5.A4 (VBUS), J5.A9 (VBUS), J5.B4 (VBUS), J5.B9 (VBUS), R28.1
/Power/~LOUT: R33.1, U5.2, U7.4
GND: C1.2, C2.2, C43.2, C44.2, J1.3 (GND), J1.5 (GND), J1.7 (GND), J1.15 (GND), J1.17 (GND), J1.18 (GND), J1.19 (GND), J1.24 (GND), J5.A1 (GND), J5.A12 (GND), J5.B1 (GND), J5.B12 (GND), J5.S1 (SHIELD), Q1.2 (E), R29.1, R32.2, R33.2, R34.2, R35.2, R36.2, R37.2, U2.1 (GND), U5.3 (GND), U7.3 (GND); also elsewhere on the board
unnamed: J5.A5 (CC1), R36.1
unnamed: J5.B5 (CC2), R37.1
unnamed: Q1.1 (B), R5.2

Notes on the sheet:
USB-C Connector
ATX PSU SR Latch
ATX Connector
USB Sensing
Always-on 3.3v

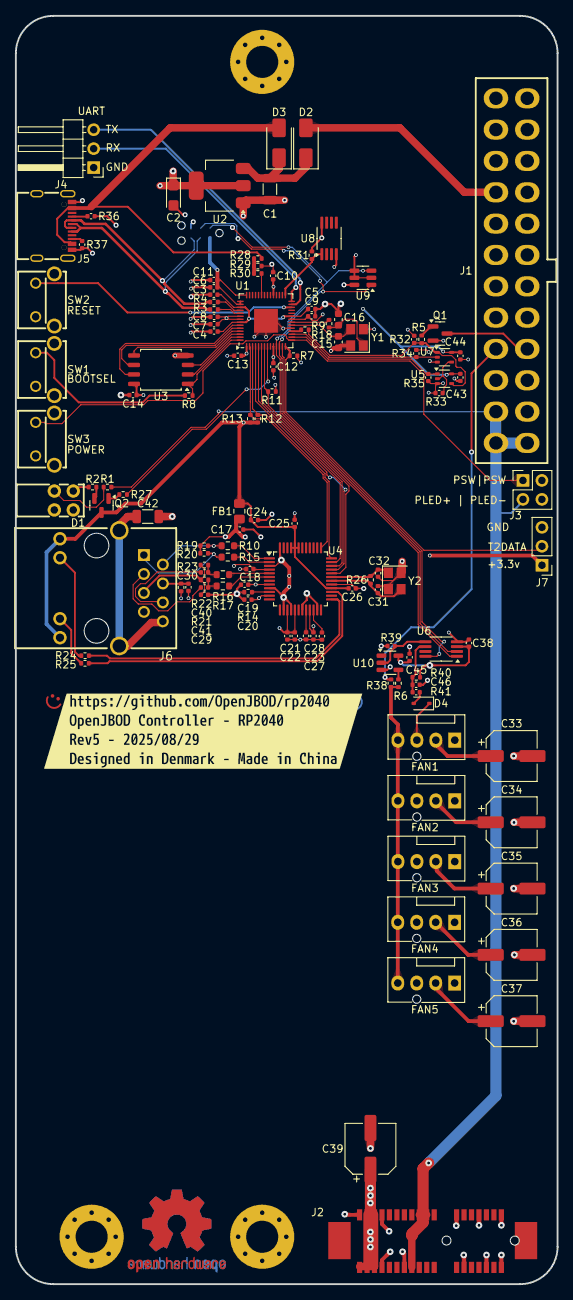
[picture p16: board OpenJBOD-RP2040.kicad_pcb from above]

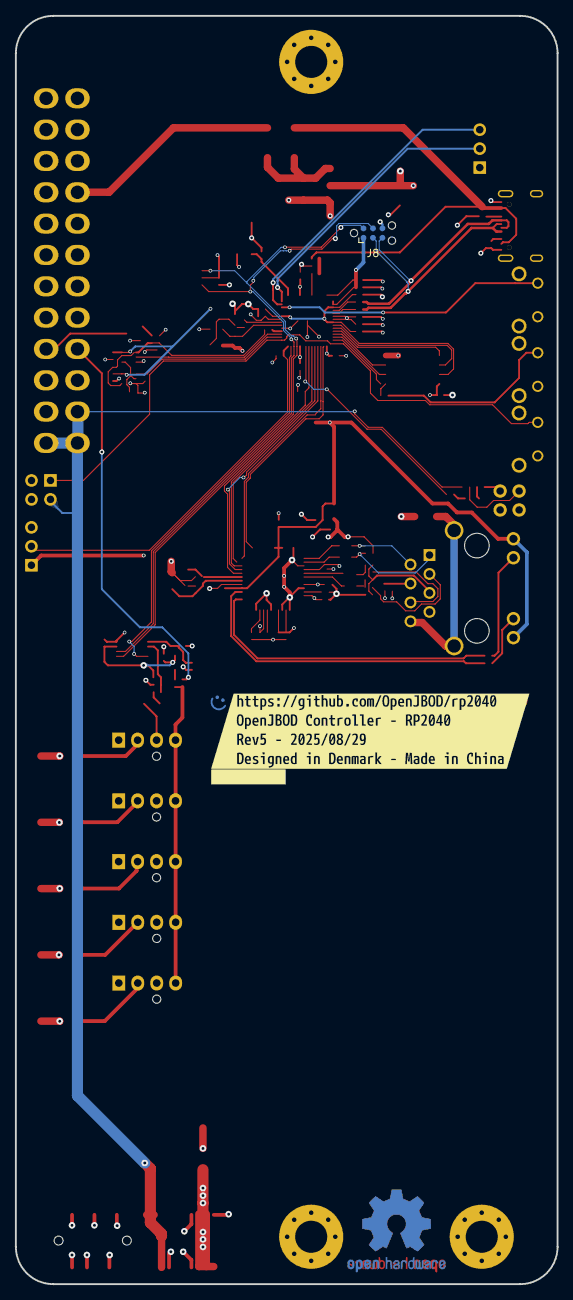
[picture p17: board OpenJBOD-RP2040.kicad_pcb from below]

Board: 4 copper layers, 72.6 x 170.0 mm, 127 parts (2 on the bottom side), 83 nets.

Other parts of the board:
kibuzzard-68B1B45A: G***; kibuzzard-68B1B45A
kibuzzard-68B1B461: G***; kibuzzard-68B1B461

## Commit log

2024-08-18 initial board upload
    [039281243.stp, 10118194-0001LF.STEP, 91618-X1.STEP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]
2024-08-18 added uart header
    [OpenJBOD-RP2040.kicad_pcb, OpenJBOD-RP2040.kicad_sch]
2024-08-18 remove serial number graphic in favor of digital sn
    [OpenJBOD-RP2040.kicad_pcb]
2024-08-29 Rev4
    Bunch of small changes, namely:
    Add onboard DS18B20 probe for more accurate temp readings without external hardware.
    Rename T1DATA to T2DATA to still allow external probes.
    Add USB power sensing circuit.
    Add SR latch for PS_ON# handling
    Add J4 UART header.
    [CONN-TH_M4202V-2X12P.step, FanController.kicad_sch, OpenJBOD-RP2040.kicad_pcb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]
2024-09-11 rev4 order version added side-mounted IO to the panel so an IO shield could theoretically be made added step models cleaned up footprints
    [CONN-TH_M4202V-2X12P.step, KEY-TH_TC-6615-6-160G.step, LED-TH_MHK2396YGBTD.step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]
2024-09-18 update ATX header for better solderability
    [OpenJBOD-RP2040.kicad_pcb]
2024-09-18 adjust UART header and rotate R27 for cleaner layout
    [OpenJBOD-RP2040.kicad_pcb]
2024-10-30 rev4.2
    Updated silkscreen info block
    Changed microUSB header to MicroXNJ
    Added RoHS and WEEE marking
    Moved BOOTSEL to rear IO
    Moved SR latch
    Moved J3 and J9 closer to the board edge, this helps to not interrupt
    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
    [FanController.kicad_sch, OpenJBOD-RP2040.kicad_pcb, OpenJBOD-RP2040.kicad_sch]
2024-12-06 added pulldowns to SR latch pins
    [FanController.kicad_sch, OpenJBOD-RP2040.kicad_sch, W5500.kicad_sch]
2024-12-06 usb-c schematic changes
    [OpenJBOD-RP2040.kicad_sch]
2024-12-09 pcb: usb-c, pull-downs
    [FanController.kicad_sch, OpenJBOD-RP2040.kicad_pcb, OpenJBOD-RP2040.kicad_sch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]
2024-12-09 sch/pcb: SR latch caps
    [OpenJBOD-RP2040.kicad_pcb, OpenJBOD-RP2040.kicad_sch]
2024-12-29 schematic cleanup
    [Environment.kicad_sch, MCU.kicad_sch, OpenJBOD-RP2040.kicad_pcb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]
2025-08-29 rev5
    Added MACROM (specific ROM holding MAC address and (optionally) board
    revision)
    Added more circuitry to protect the EMC2301, allowing for use with fans
    with internal pull-ups.
    Added USB-C
    [Environment.kicad_sch, MCU.kicad_sch, OpenJBOD-RP2040.kicad_pcb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]
